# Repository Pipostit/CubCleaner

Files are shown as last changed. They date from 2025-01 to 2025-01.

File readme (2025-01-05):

# Goal
This project aim to repair a broken vacuum cleaner (Taurus : UNLIMITED 29.0 LITHIUM)
- Battery and PCB are dead. I suspect a short on the mainboard
- Solution: Redo the pcb and the battery pack

8 li-on cell were used in the original holder, an BMs is used outside of the scope of this design (https://www.aliexpress.com/item/1005004441321493.html)

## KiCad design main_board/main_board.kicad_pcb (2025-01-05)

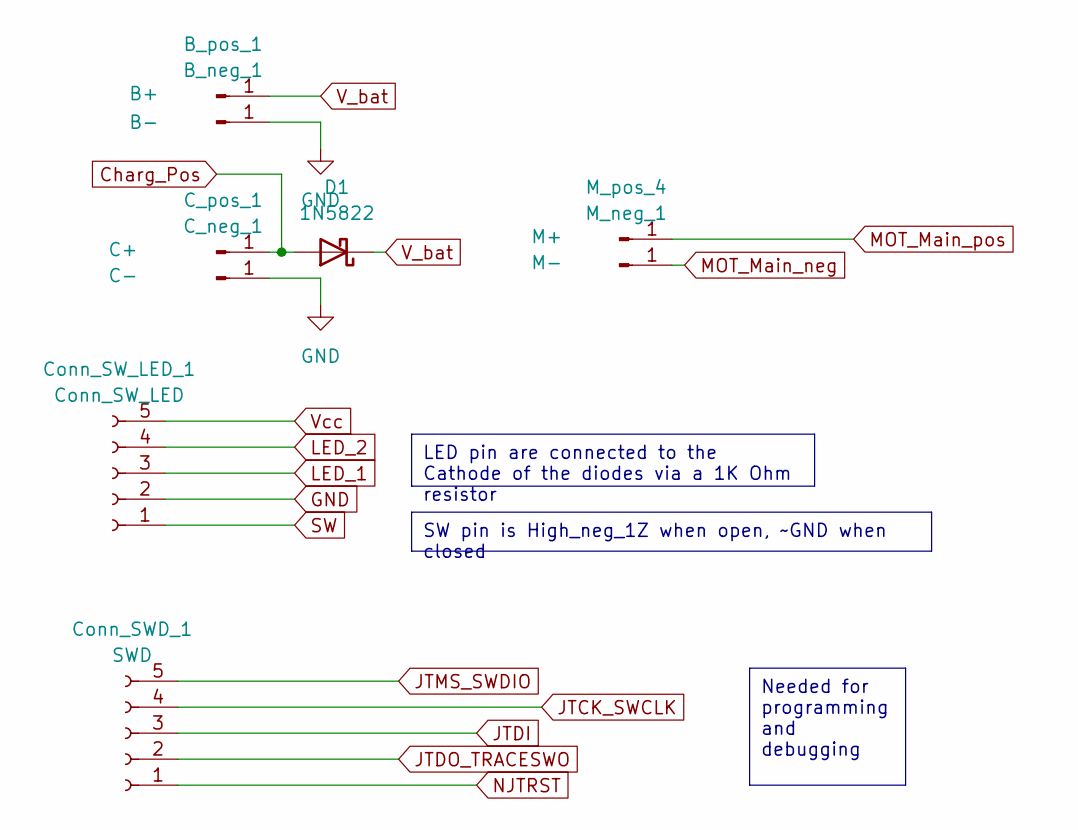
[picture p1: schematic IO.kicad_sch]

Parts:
B_neg_1: B-; SolderWire-1.5sqmm_1x01_D1.7mm_OD3.9mm
B_pos_1: B+; SolderWire-1.5sqmm_1x01_D1.7mm_OD3.9mm
C_neg_1: C-; SolderWire-1.5sqmm_1x01_D1.7mm_OD3.9mm
C_pos_1: C+; SolderWire-1.5sqmm_1x01_D1.7mm_OD3.9mm
Conn_SWD_1: SWD; JST_EH_S5B-EH_1x05_P2.50mm_Horizontal
Conn_SW_LED_1: Conn_SW_LED; JST_EH_S5B-EH_1x05_P2.50mm_Horizontal
D1: 1N5822; D_SMA
M_neg_1: M-; SolderWire-1.5sqmm_1x01_D1.7mm_OD3.9mm
M_pos_4: M+; SolderWire-1.5sqmm_1x01_D1.7mm_OD3.9mm

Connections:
Charg_Pos: C_pos_1.1, D1.2 (A)
GND: B_neg_1.1, C_neg_1.1, Conn_SW_LED_1.2; also elsewhere on the board
JTCK_SWCLK: Conn_SWD_1.4; also elsewhere on the board
JTDI: Conn_SWD_1.3; also elsewhere on the board
JTDO_TRACESWO: Conn_SWD_1.2; also elsewhere on the board
JTMS_SWDIO: Conn_SWD_1.5; also elsewhere on the board
MOT_Main_neg: M_neg_1.1; also elsewhere on the board
MOT_Main_pos: M_pos_4.1; also elsewhere on the board
NJTRST: Conn_SWD_1.1; also elsewhere on the board
SW: Conn_SW_LED_1.1; also elsewhere on the board
V_bat: B_pos_1.1, D1.1 (K); also elsewhere on the board
Vcc: Conn_SW_LED_1.5; also elsewhere on the board

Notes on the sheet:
Needed for programming and debugging
SW pin is High_neg_1Z when open, ~GND when closed
LED pin are connected to the Cathode of the diodes via a 1K Ohm resistor

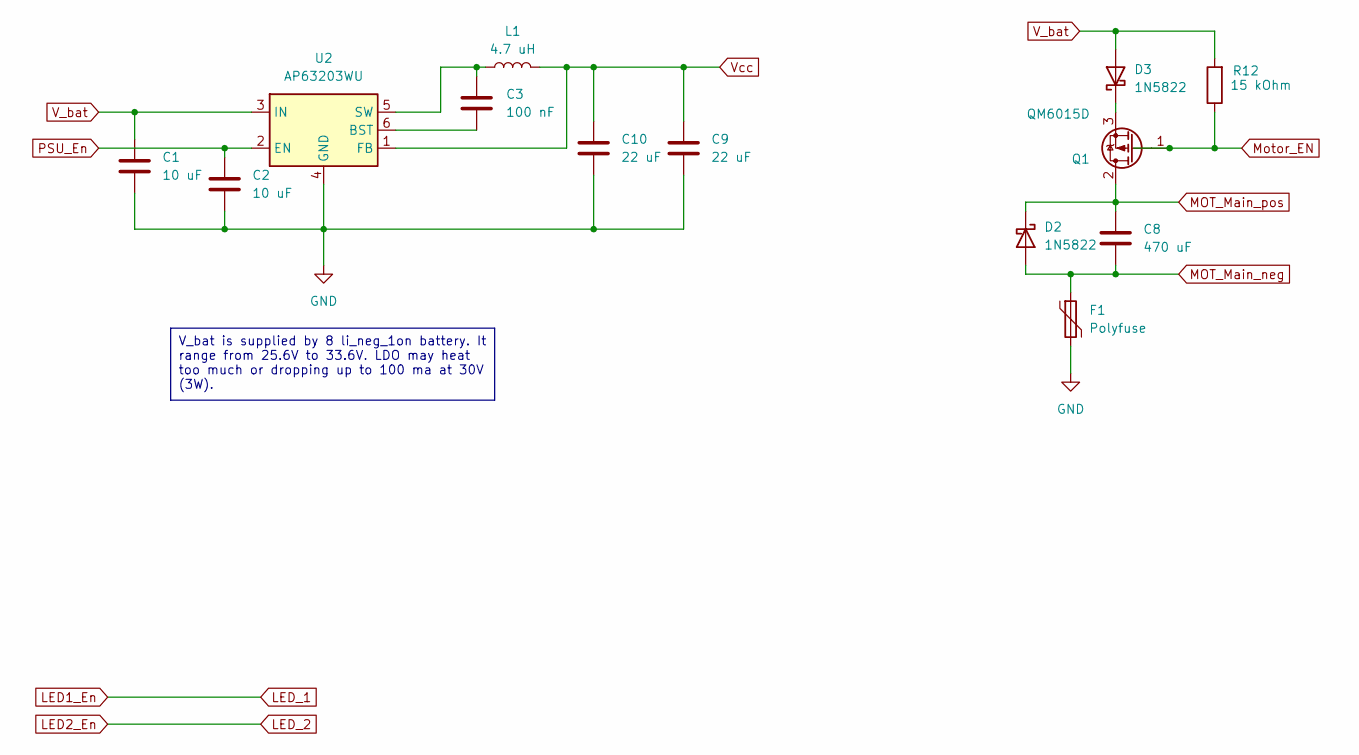
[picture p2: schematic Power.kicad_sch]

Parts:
C1, C2: 10 uF; C_0201_0603Metric_Pad0.64x0.40mm_HandSolder
C3: 100 nF; C_0201_0603Metric_Pad0.64x0.40mm_HandSolder
C8: 470 uF; C_0603_1608Metric_Pad1.08x0.95mm_HandSolder
C9, C10: 22 uF; C_0201_0603Metric_Pad0.64x0.40mm_HandSolder
D2, D3: 1N5822; D_SMA
F1: Polyfuse; R_1206_3216Metric_Pad1.30x1.75mm_HandSolder
L1: 4.7 uH; L_0603_1608Metric_Pad1.05x0.95mm_HandSolder
Q1: QM6015D; TO-252-2
R12: 15 kOhm; R_0201_0603Metric_Pad0.64x0.40mm_HandSolder
U2: AP63203WU; TSOT-23-6

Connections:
GND: C1.2, C2.2, C9.2, C10.2, F1.2, U2.4 (GND); also elsewhere on the board
MOT_Main_neg: C8.2, D2.2 (A), F1.1; also elsewhere on the board
MOT_Main_pos: C8.1, D2.1 (K), Q1.2 (D); also elsewhere on the board
Motor_EN: Q1.1 (G), R12.1; also elsewhere on the board
unnamed: D3.1 (K), Q1.3 (S)
unnamed: C3.2, U2.6 (BST)
unnamed: C3.1, L1.1, U2.5 (SW)
PSU_En: C2.1, U2.2 (EN); also elsewhere on the board
V_bat: C1.1, D3.2 (A), R12.2, U2.3 (IN); also elsewhere on the board
Vcc: C9.1, C10.1, L1.2, U2.1 (FB); also elsewhere on the board

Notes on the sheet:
V_bat is supplied by 8 li_neg_1on battery. It range from 25.6V to 33.6V. LDO may heat too much or dropping up to 100 ma at 30V (3W).

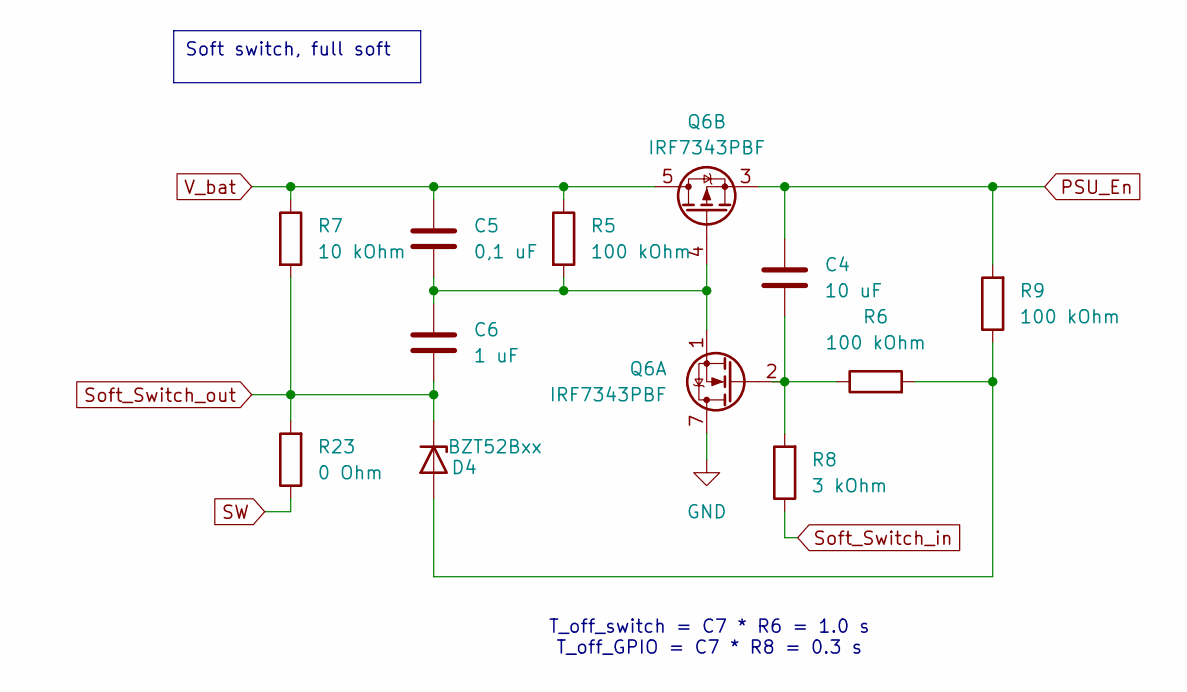
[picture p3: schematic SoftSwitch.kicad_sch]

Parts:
C4: 10 uF; C_0201_0603Metric_Pad0.64x0.40mm_HandSolder
C5: 0,1 uF; C_0201_0603Metric_Pad0.64x0.40mm_HandSolder
C6: 1 uF; C_0201_0603Metric_Pad0.64x0.40mm_HandSolder
D4: BZT52Bxx; D_SOD-123F
Q6: IRF7343PBF; SOIC-8_3.9x4.9mm_P1.27mm
R5, R6, R9: 100 kOhm; R_0201_0603Metric_Pad0.64x0.40mm_HandSolder
R7: 10 kOhm; R_0201_0603Metric_Pad0.64x0.40mm_HandSolder
R8: 3 kOhm; R_0201_0603Metric_Pad0.64x0.40mm_HandSolder
R23: 0 Ohm; R_0201_0603Metric_Pad0.64x0.40mm_HandSolder

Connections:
GND: Q6.7 (D), Q6.8 (D); also elsewhere on the board
unnamed: D4.2 (A), R6.2, R9.1
unnamed: C4.1, Q6.2 (G), R6.1, R8.2
unnamed: C5.2, C6.2, Q6.1 (S), Q6.4 (G), R5.2
PSU_En: C4.2, Q6.3 (1), R9.2; also elsewhere on the board
SW: R23.1; also elsewhere on the board
Soft_Switch_in: R8.1; also elsewhere on the board
Soft_Switch_out: C6.1, D4.1 (K), R7.2, R23.2; also elsewhere on the board
V_bat: C5.1, Q6.5 (D), Q6.6 (D), R5.1, R7.1; also elsewhere on the board

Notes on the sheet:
Soft switch, full soft
T_off_switch = C7 * R6 = 1.0 s T_off_GPIO = C7 * R8 = 0.3 s

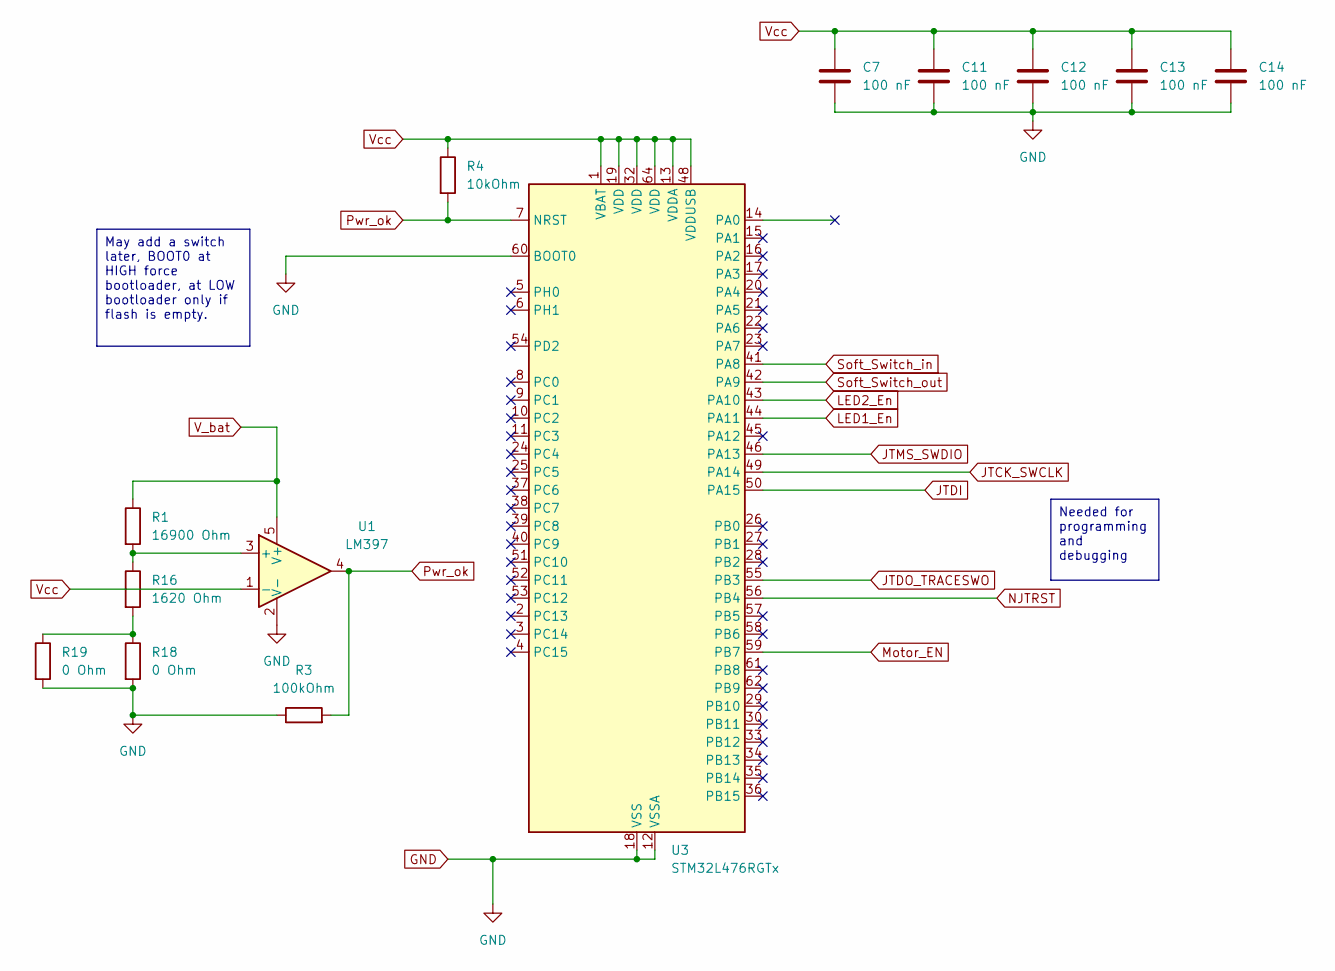
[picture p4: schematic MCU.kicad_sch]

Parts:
C7, C11, C12, C13, C14: 100 nF; C_0201_0603Metric_Pad0.64x0.40mm_HandSolder
R1: 16900 Ohm; R_0201_0603Metric
R3: 100kOhm; R_0201_0603Metric_Pad0.64x0.40mm_HandSolder
R4: 10kOhm; R_0201_0603Metric_Pad0.64x0.40mm_HandSolder
R16: 1620 Ohm; R_0201_0603Metric
R18, R19: 0 Ohm; R_0201_0603Metric_Pad0.64x0.40mm_HandSolder
U1: LM397; SOT-23-5
U3: STM32L476RGTx; LQFP-64_10x10mm_P0.5mm

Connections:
GND: C7.2, C11.2, C12.2, C13.2, C14.2, R3.1, R18.2, R19.2, U1.2 (V-), U3.12 (VSSA), U3.18 (VSS), U3.31 (VSS), U3.47 (VSS), U3.60 (BOOT0), U3.63 (VSS); also elsewhere on the board
JTCK_SWCLK: U3.49 (PA14); also elsewhere on the board
JTDI: U3.50 (PA15); also elsewhere on the board
JTDO_TRACESWO: U3.55 (PB3); also elsewhere on the board
JTMS_SWDIO: U3.46 (PA13); also elsewhere on the board
Motor_EN: U3.59 (PB7); also elsewhere on the board
NJTRST: U3.56 (PB4); also elsewhere on the board
unnamed: R16.2, R18.1, R19.1
unnamed: R1.2, R16.1, U1.3 (+)
Pwr_ok: R3.2, R4.2, U1.4, U3.7 (NRST)
Soft_Switch_in: U3.41 (PA8); also elsewhere on the board
Soft_Switch_out: U3.42 (PA9); also elsewhere on the board
V_bat: R1.1, U1.5 (V+); also elsewhere on the board
Vcc: C7.1, C11.1, C12.1, C13.1, C14.1, R4.1, U1.1 (-), U3.1 (VBAT), U3.13 (VDDA), U3.19 (VDD), U3.32 (VDD), U3.48 (VDDUSB), U3.64 (VDD); also elsewhere on the board

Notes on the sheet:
Needed for programming and debugging
May add a switch later, BOOT0 at HIGH force bootloader, at LOW bootloader only if flash is empty.

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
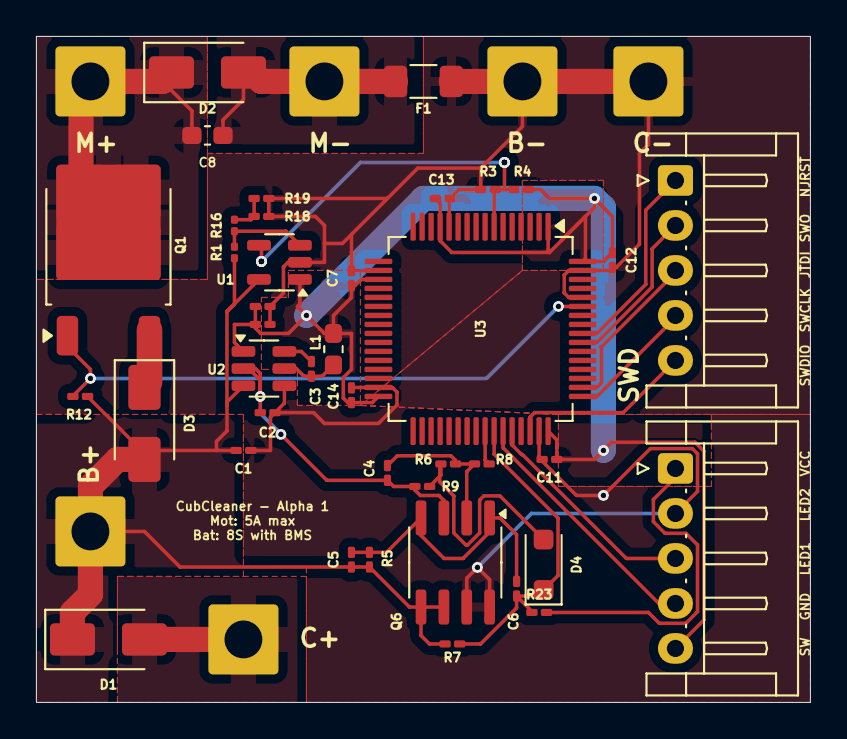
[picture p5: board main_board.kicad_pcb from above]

Board: 2 copper layers, 43.0 x 37.0 mm, 46 parts (0 on the bottom side), 27 nets.

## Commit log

2025-01-05 First iteration of the PCB
    [IO.kicad_sch, MCU.kicad_sch, Power.kicad_sch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]
2025-01-05 Change JST connector for horizontal connector, reuse JST connector for debugging, correct pin order.
    [IO.kicad_sch, MCU.kicad_sch, main_board.kicad_pcb]
